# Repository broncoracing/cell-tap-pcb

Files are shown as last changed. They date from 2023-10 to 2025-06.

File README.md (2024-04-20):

# Bronco Racing Segment Monitor PCB

This repository contains the hardware design, firmware, and software calibration scripts for the segment monitor PCB.

The segment monitor contains an STM32f103R8T6 microcontroller which interfaces 15 ADCs (12 external for monitoring cell temperatures and 3 onboard on the PCB.)
A separate break-away board for digital and power isolation is also included.

## Hardware details

The thermistor measurement circuit consists of a 10k thermistor (or connector for a thermistor), a precision 10k reference resistor, and a filter capacitor (The filter capacitor is mostly important to prevent measurement errors due to the changing input impedance of the microcontroller's analog pins when they sample the voltage, this is likely a very small effect that wouldn't cause large errors anyway).

The reference resistor and thermistor form a voltage divider circuit, which allows the resistance of the thermistor to be determined by reading the center voltage.

The circuit is designed specifically to work with 10k NTC thermistors, but it would likely work with any thermistor with a resistance in the 1k-100k range.

Each external thermistor connector also has an LED located next to the connector. This LED indicates whether the thermistor's resistance is valid. If the thermistor is within a reasonable range, the LED will be off. If the microcontroller detects too high or low of a voltage (indicating a short circuit or disconnected thermistor) the LED is turned on. Upon powering up the LEDs will all turn on and off in sequence to verify that the LEDs themselves function correctly.

On the back side of the board (opposite the microcontroller) each cell tap connection connects to an SMD fuse and a trace which leads to the cell tap connector. These fuses are located close to the cell tap connection to meet FSAE rules for fusing of tractive system wires, and eliminate the need for inline fuses on each cell tap wire. 
Due to a minor design oversight, the fuses on the endmost cell taps can be damaged or knocked off the board if the busbars for the Radlok maintenance plugs are rotated too far inwards when the segment is being assembled. Take care when assembling or disassembling the segments to avoid this issue.

## Firmware documentation
The firmware reads data from all the connected thermistors and sends them over the CAN bus at 100ms intervals.

To avoid overloading CAN bus with too many concurrent messages, each segment sends out only 4 thermistor values in each message, and rotates which thermistor temperatures are sent out in each message.

The segment PCB firmware also includes a thermistor calibration routine, which stores measured ADC values for three different temperatures  the Steinhart-Hart equation as described below in the Performance Testing & Analysis section. To perform this calibration, a simple CAN protocol similar to the one utilized by the CAN bootloader was developed. This protocol consists of four commands to perform the following actions:
- Clear calibration data
- Record resistances at a given temperature
- Calculate Steinhart-Hart parameters based on three temperature values
- Read out calibration data over CAN bus and print it to the console

In order to simplify the user experience, a Python command line application was developed to execute these commands and interpret the response sent back over the CAN bus.
This script is located at `firmware/scripts/calibrate.py`. Since I was too lazy to make it automatically detect the CAN bus interface, you'll have to manually set it in the script (or upgrade the script to use a command line parameter), it will be something like `/dev/ttyACM*` on linux.

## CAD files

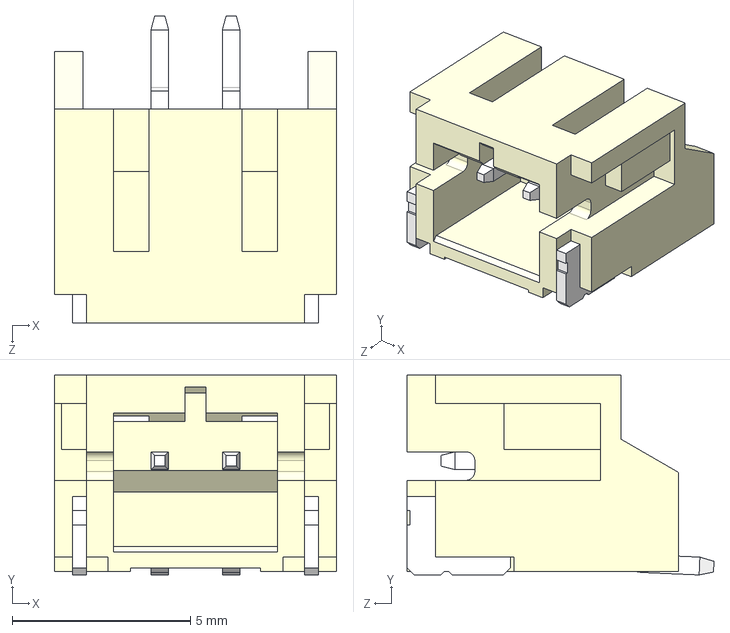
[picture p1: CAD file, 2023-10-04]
3d/S2B-PH-SM4-TB(LF)(SN)--3DModel-STEP-56544.STEP
7.90 x 5.60 x 8.60 mm

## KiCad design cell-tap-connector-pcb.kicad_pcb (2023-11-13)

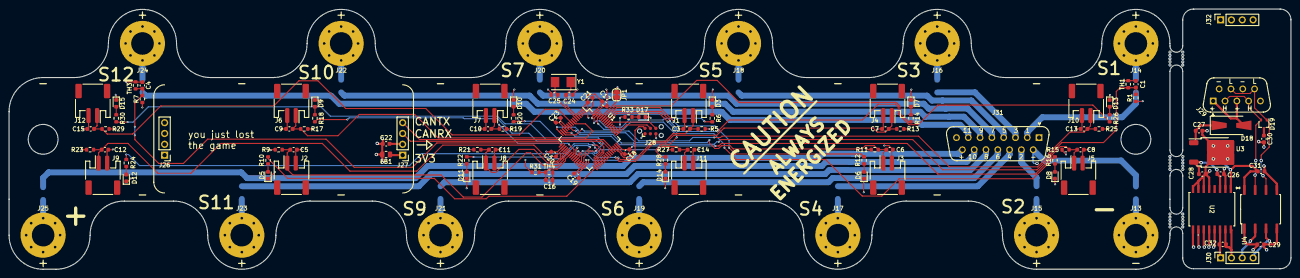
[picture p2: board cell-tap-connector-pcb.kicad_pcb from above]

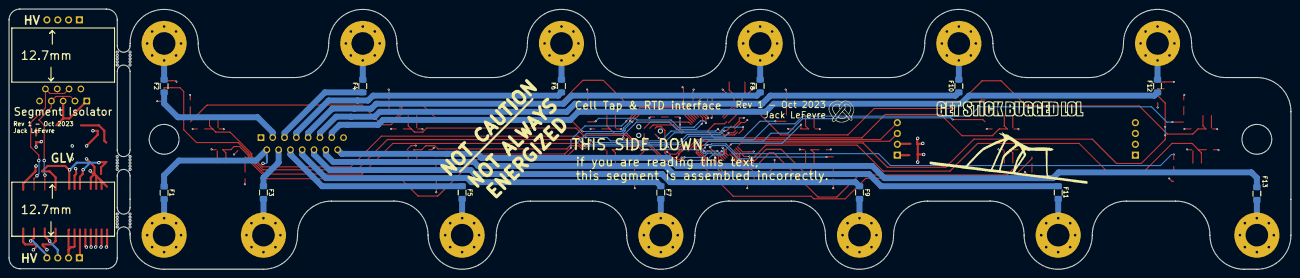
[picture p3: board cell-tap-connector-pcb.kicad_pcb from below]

Board: 4 copper layers, 300.9 x 61.1 mm, 133 parts (14 on the bottom side), 89 nets.

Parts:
C1, C3, C4, C5, C6, C7, C8, C9, C10, C11, C12, C13, C14, C15, C16, C22, C27: 1u; C_0603_1608Metric
C17: 4u7; C_0603_1608Metric
C18, C19, C20, C21, C23, C28, C29, C30, C31: 100n; C_0603_1608Metric
C24, C25: 30p; C_0603_1608Metric
C26, C32: 10u; C_0603_1608Metric
D3, D5, D6, D7, D8, D9, D10, D11, D12, D13, D14, D15, D17: RED 0603; LED_0603_1608Metric
D18: SSB43L; D_SMA-SMB_Universal_Handsoldering
D19: ESDCAN24-2BLY; SOT-323_SC-70
F1, F2, F3, F4, F5, F6, F7, F8, F9, F10, F11, F12, F13: 2A 63VDC 1206; Fuse_1206_3216Metric_Pad1.42x1.75mm_HandSolder
FB1: 100R@100MHz; R_0805_2012Metric
J1, J2, J3, J4, J5, J6, J7, J8, J9, J10, J11, J12: JST S2B-PH-SM4-TB; JST_PH_S2B-PH-SM4-TB_1x02-1MP_P2.00mm_Horizontal
J13, J14, J15, J16, J17, J18, J19, J20, J21, J22, J23, J24, J25: Mounting Hole M5; MountingHole_5.3mm_M5_Pad_Via
J26, J27: Pin Header 0.1" 01x04; PinHeader_1x04_P2.54mm_Vertical
J28: TC2030; Tag-Connect_TC2030-IDC-NL_2x03_P1.27mm_Vertical
J29: Norcomp 172-009-243R021; DSUB-9_Female_Vertical_P2.77x2.84mm
J30, J32: Pin Socket 0.1" 01x04; PinSocket_1x04_P2.54mm_Vertical
J31: 172-015-243R021; DSUB-15_Female_Vertical_P2.77x2.84mm
JP1: SolderJumper_2_Bridged; SolderJumper-2_P1.3mm_Bridged_RoundedPad1.0x1.5mm
NT1: NetTie_2; NetTie-2_SMD_Pad0.5mm
R1, R5, R7, R9, R11, R13, R15, R17, R19, R21, R23, R25, R27, R29, R31: 10k 0.1%; R_0603_1608Metric
R6, R10, R12, R14, R16, R18, R20, R22, R24, R26, R28, R30, R33: 1k; R_0603_1608Metric
TH1, TH3, TH4: 10k NTC ERT-J1VR103J; R_0603_1608Metric
U1: STM32F103R8T6; LQFP-64_10x10mm_P0.5mm
U2: UCC12040DVE; SO_0DVER_TEX
U3: L7805CDT; TO-252-2
U4: ISO1050DUB; SOP-8_6.62x9.15mm_P2.54mm
Y1: 8MHz 20pF; Crystal_SMD_5032-2Pin_5.0x3.2mm
mouse-bite-3mm-slot, mouse-bite-3mm-slot#2, mouse-bite-3mm-slot#3: VAL**; mouse-bite-3mm-slot

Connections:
+3.3VA: C22.1, C23.1, FB1.2, R1.1, R5.1, R7.1, R9.1, R11.1, R13.1, R15.1, R17.1, R19.1, R21.1, R23.1, R25.1, R27.1, R29.1, R31.1, U1.13 (VDDA)
+3V3: C17.1, C18.1, C19.1, C20.1, C21.1, FB1.1, J27.1, J28.1 (VCC), U1.1 (VBAT), U1.19 (VDD), U1.32 (VDD), U1.48 (VDD), U1.64 (VDD)
/Cell PCB/HSE_IN: C24.1, U1.5 (PD0), Y1.1
/Cell PCB/HSE_OUT: C25.1, U1.6 (PD1), Y1.2
/Cell PCB/cell1-p: F2.1, J31.2
/Cell PCB/cell2-p: F3.1, J31.10
/Cell PCB/cell3-p: F4.1, J31.3
/Cell PCB/cell4-p: F5.1, J31.11 (P111)
/Cell PCB/cell5-p: F6.1, J31.4
/Cell PCB/cell6-p: F7.1, J31.12
/Cell PCB/cell7-p: F8.1, J31.5
/Cell PCB/cell8-p: F9.1, J31.13
/Cell PCB/cell9-p: F10.1, J31.6
/Cell PCB/cell10-p: F11.1, J31.14
/Cell PCB/cell11-p: F12.1, J31.7
/Cell PCB/segment-n: F1.1, J31.9, NT1.1
/Cell PCB/segment-p: F13.1, J31.15
/Cell PCB/status-led: R33.1, U1.50 (PA15)
/Isolator/3v3@HV: C29.1, C32.1, J30.1, U2.14 (VISO), U4.1 (VCC1)
/Isolator/5V0@GLV: C26.1, C28.1, C31.2, U2.1 (EN), U2.3 (VINP), U3.3 (OUT), U4.8 (VCC2)
/Isolator/CANH: D19.2 (A2), J29.2, J29.4, U4.7 (CANH)
/Isolator/CANL: D19.1 (A1), J29.7, J29.9, U4.6 (CANL)
/Isolator/CANRX: J30.3, U4.2 (RXD)
/Isolator/CANTX: J30.4, U4.3 (TXD)
/Isolator/GLV+: D18.2 (A), J29.1, J29.3
/Isolator/GLV-: C26.2, C27.2, C28.2, C30.2, C31.1, J29.6, J29.8, U2.2 (GNDP), U2.5 (SYNC_OK), U2.6 (NC), U2.7 (NC), U2.8 (NC), U3.2 (GND), U4.5 (GND2)
/Isolator/GND@HV: C29.2, C32.2, J30.2, U2.9 (GNDS), U2.10 (NC), U2.11 (NC), U2.12 (NC), U2.13 (SEL), U2.15 (GNDS), U2.16 (GNDS), U4.4 (GND1)
CANRX: J27.3, U1.44 (PA11)
CANTX: J27.4, U1.45 (PA12)
GND: C1.2, C3.2, C4.2, C5.2, C6.2, C7.2, C8.2, C9.2, C10.2, C11.2, C12.2, C13.2, C14.2, C15.2, C16.2, C17.2, C18.2, C19.2, C20.2, C21.2, C22.2, C23.2, C24.2, C25.2, D3.1 (K), D5.1 (K), D6.1 (K), D7.1 (K), D8.1 (K), D9.1 (K), D10.1 (K), D11.1 (K), D12.1 (K), D13.1 (K), D14.1 (K), D15.1 (K), D17.1 (K), J1.2, J2.2, J3.2, J4.2, J5.2, J6.2, J7.2, J8.2, J9.2, J10.2, J11.2, J12.2, J27.2, J28.5 (GND), JP1.1 (A), NT1.2, TH1.2, TH3.2, TH4.2, U1.12 (VSSA), U1.18 (VSS), U1.31 (VSS), U1.47 (VSS), U1.63 (VSS)
unnamed: D3.2 (A), R6.2
unnamed: D5.2 (A), R10.2
unnamed: D6.2 (A), R12.2
unnamed: D7.2 (A), R14.2
unnamed: D8.2 (A), R16.2
unnamed: D9.2 (A), R18.2
unnamed: D10.2 (A), R20.2
unnamed: D11.2 (A), R22.2
unnamed: D12.2 (A), R24.2
unnamed: D13.2 (A), R26.2
unnamed: D14.2 (A), R28.2
unnamed: D15.2 (A), R30.2
unnamed: D17.2 (A), R33.2
unnamed: C27.1, D18.1 (K), U3.1 (IN)
unnamed: C30.1, D19.3 (common)
unnamed: F1.2, J13.1
unnamed: F2.2, J14.1
unnamed: F3.2, J15.1
unnamed: F4.2, J16.1
unnamed: F5.2, J17.1
unnamed: F6.2, J18.1
unnamed: F7.2, J19.1
unnamed: F8.2, J20.1
unnamed: F9.2, J21.1
unnamed: F10.2, J22.1
unnamed: F11.2, J23.1
unnamed: F12.2, J24.1
unnamed: F13.2, J25.1
unnamed: JP1.2 (B), U1.60 (BOOT0)
STAT0: R16.1, U1.56 (PB4)
STAT1: R26.1, U1.57 (PB5)
STAT2: R12.1, U1.58 (PB6)
STAT3: R14.1, U1.59 (PB7)
STAT4: R28.1, U1.61 (PB8)
STAT5: R6.1, U1.62 (PB9)
STAT6: R22.1, U1.29 (PB10)
STAT7: R20.1, U1.30 (PB11)
STAT8: R10.1, U1.33 (PB12)
STAT9: R18.1, U1.34 (PB13)
STAT10: R24.1, U1.35 (PB14)
STAT11: R30.1, U1.36 (PB15)
SWCLK: J28.4 (SWCLK), U1.49 (PA14)
SWDIO: J28.2 (SWDIO), U1.46 (PA13)
SWO: J28.6 (SWO), U1.55 (PB3)
TEMP0: C8.1, J5.1, R15.2, U1.14 (PA0)
TEMP1: C13.1, J10.1, R25.2, U1.15 (PA1)
TEMP2: C6.1, J3.1, R11.2, U1.16 (PA2)
TEMP3: C7.1, J4.1, R13.2, U1.26 (PB0)
TEMP4: C14.1, J11.1, R27.2, U1.27 (PB1)
TEMP5: C3.1, J1.1, R5.2, U1.25 (PC5)
TEMP6: C11.1, J8.1, R21.2, U1.21 (PA5)
TEMP7: C10.1, J7.1, R19.2, U1.24 (PC4)
TEMP8: C5.1, J2.1, R9.2, U1.22 (PA6)
TEMP9: C9.1, J6.1, R17.2, U1.8 (PC0)
TEMP10: C12.1, J9.1, R23.2, U1.20 (PA4)
TEMP11: C15.1, J12.1, R29.2, U1.9 (PC1)
TEMP12: C4.1, R7.2, TH3.1, U1.17 (PA3)
TEMP13: C1.1, R1.2, TH1.1, U1.11 (PC3)
TEMP14: C16.1, R31.2, TH4.1, U1.23 (PA7)

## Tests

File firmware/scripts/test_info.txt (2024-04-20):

--- TEST 1 ---
File: candump-2024-04-06 211554.log
Starting water temp: 46.0C
Start time: 9:18pm
Ending temp: 46.2C
Ending time: 9:24
(timestamp 1712453035.319857)

Unsure of calibration accuracy for this test. The first segment cooled much less; this indicates that higher flow rate is required.
--- TEST 2 ---
File: candump-2024-04-06_214447.log 
Start time: 9:45
(timestamp 1712454359.600237)
Start water temp: 48.4
Temp switch time: 9:51
(timestamp 1712454697.084706)
flow rate tests: 5gal in 1:18 (14.8in^3/sec)
switched to cool water.
Flow rate tests: 5gal in 1:30 (12.8in^3/sec)
outlet water temp 25.5 30 sec after start
Water flow stop time: 9:55
(timestamp 1712454924.238978)
End inlet water temp: 11.8C

It appears the segment wasn't calibrated well at room temperature; it thought it started the test out at 33C :(

--- TEST 3 ---
File: candump-2024-04-06_221804.log
Starting time: 10:18
(timestamp 1712456355.978423)
Initial water temp: 47.3C
Room temp: 24.5C
Flow rate: 1:25 for 5gal (13.6in^3/s)
Switched to cool water at 10:23
(timestamp 1712456619.035202)
flow rate: 1:40 for 5gal (11.55 in^3/sec)
End time: 10:29
(Timestamp 1712456964.507980)
End water temp: 10.3C

This test went much more smoothly. The cell temperature sensors were calibrated to room temp (24C) a few minutes before the test.

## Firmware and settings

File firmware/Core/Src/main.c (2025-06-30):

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
/* Includes ------------------------------------------------------------------*/
#include "main.h"

/* USER CODE BEGIN Includes */
#include "can-ids/CAN.h"
#include <string.h>
#include <math.h>
/* USER CODE END Includes */

/* USER CODE BEGIN PD */

// TODO Read from flash
uint32_t BOARD_ID = 0;
/* USER CODE END PD */

ADC_HandleTypeDef hadc1;
DMA_HandleTypeDef hdma_adc1;

CAN_HandleTypeDef hcan;

void SystemClock_Config(void);
static void MX_GPIO_Init(void);
static void MX_DMA_Init(void);
static void MX_ADC1_Init(void);
static void MX_CAN_Init(void);
/* USER CODE BEGIN 0 */
GPIO_TypeDef* status_ports[N_STATUS_LEDS] = {
  STAT0_GPIO_Port,
  STAT1_GPIO_Port,
  STAT2_GPIO_Port,
  STAT3_GPIO_Port,
  STAT4_GPIO_Port,
  STAT5_GPIO_Port,
  STAT6_GPIO_Port,
  STAT7_GPIO_Port,
  STAT8_GPIO_Port,
  STAT9_GPIO_Port,
  STAT10_GPIO_Port,
  STAT11_GPIO_Port,
};
uint16_t status_pins[N_STATUS_LEDS] = {
  STAT0_Pin,
  STAT1_Pin,
  STAT2_Pin,
  STAT3_Pin,
  STAT4_Pin,
  STAT5_Pin,
  STAT6_Pin,
  STAT7_Pin,
  STAT8_Pin,
  STAT9_Pin,
  STAT10_Pin,
  STAT11_Pin,
};

uint8_t adc_to_channel_mapping[N_ADC_CHANNELS] = {
  0, 1, 2, 12, 10, 6, 8, 14, 3, 4, 9, 11, 13, 7, 5
};



volatile uint16_t adc_readings[N_ADC_CHANNELS];

int16_t temperatures[N_ADC_CHANNELS];

// Orion BMS CAN data
uint8_t orion_data_ready = 0; // stores whether data is available to send yet
const uint8_t thermistor_module_number = 0;
int8_t pack_min_temperature; // in degrees C
uint8_t pack_min_idx;
int8_t pack_max_temperature; // in degrees C
uint8_t pack_max_idx;
int32_t pack_temp_sum; // for calculating average temperature
uint8_t pack_temp_samples;
const uint8_t thermistor_count = 12 * 7;

const uint8_t orion_bms_address_claim[8] = {
  0xF3, 0x00, 0x80, 0xF3, 0x00, 0x40, 0x1E, 0x90
};


uint32_t write_cal_data(struct ThermistorCal_T* data);


float compute_resistance(uint16_t adc_reading) {
  float adc_float = (float) adc_reading;
  float voltage_fac = adc_float / ((float) 0x1000); // input voltage as a fraction of VDDA
  const float ref_resistance = 10000.0; // precision reference resistor value
  float rtd_resistance = ref_resistance * ((1.0 / voltage_fac) - 1);
  return rtd_resistance;
}

float c2k(float c) {
    return c + 273.15;
}
float k2c(float k) {
    return k - 273.15;
}

struct SteinhartHartParameters compute_parameters(float r1, float t1, float r2, float t2, float r3, float t3) {
    float ln_r1 = logf(r1);
    float ln_r2 = logf(r2);
    float ln_r3 = logf(r3);

    float Y_1 = 1.0 / c2k(t1);
    float Y_2 = 1.0 / c2k(t2);
    float Y_3 = 1.0 / c2k(t3);

    float gamma_2 = (Y_2 - Y_1) / (ln_r2 - ln_r1);
    float gamma_3 = (Y_3 - Y_1) / (ln_r3 - ln_r1);

    float C = ((gamma_3 - gamma_2) / (ln_r3 - ln_r2)) * 1.0 / (ln_r1 + ln_r2 + ln_r3);

    float B = gamma_2 - C * (ln_r1 * ln_r1 + ln_r1 * ln_r2 + ln_r2 * ln_r2);

    float A = Y_1 - (B + C * ln_r1 * ln_r1) * ln_r1;

    struct SteinhartHartParameters params = {A,B,C};
    return params;
}

float compute_temperature(struct SteinhartHartParameters* p, float r) {
  float ln_r = logf(r);
  float t_inv = p->A + p->B * ln_r + p->C * ln_r * ln_r * ln_r;
  float temp_kelvin = 1.0 / t_inv;
  return k2c(temp_kelvin);
}

void can_send_float(uint8_t errno, float f1) {
  // Message header
  CAN_TxHeaderTypeDef m;
  // Use standard ID
  m.IDE = CAN_ID_STD;
  // Set message ID
  m.StdId = CELL_TAP_CAL_RESP_ID + BOARD_ID;
  // Use CAN_RTR_DATA to transmit data
  // We may use CAN_RTR_REMOTE to request things to send data in the future
  m.RTR = CAN_RTR_DATA;
  // Amount of data
  m.DLC = 8;

  // Data to send
  uint8_t data_u8[8];

  uint32_t* int_value = (uint32_t*) &f1;
  data_u8[4] = (*int_value >> 24) & 0xff;
  data_u8[5] = (*int_value >> 16) & 0xff;
  data_u8[6] = (*int_value >> 8) & 0xff;
  data_u8[7] = (*int_value) & 0xff;
  data_u8[0] = errno;
  data_u8[1] = 0;
  data_u8[2] = 0;
  data_u8[3] = 0;

  // Send a message
  uint32_t mailbox;
  HAL_CAN_AddTxMessage(&hcan, &m, data_u8, &mailbox);
  
  // Wait for message to be sent. This is usually not needed.
  while (HAL_CAN_IsTxMessagePending(&hcan, mailbox));
}

uint8_t cal_cmd(uint8_t cmd, float value) {
  uint8_t errno = 0;
  
  // read current calibration from flash
  struct ThermistorCal_T current_cal;
  struct ThermistorCal_T* memcpy_source = CAL_TABLE;
  memcpy(&current_cal, memcpy_source, sizeof(struct ThermistorCal_T));
  switch(cmd) {
    case 0:
      // clear calibration
      struct ThermistorCal_T blank_cal = {0};
      if(write_cal_data(&blank_cal) > 0) errno = 1;
      break;
    case 1:
    case 2:
    case 3:
      current_cal.temps[cmd - 1] = value;
      for(uint8_t i = 0; i < N_ADC_CHANNELS; ++i) {
        // TODO use filtered adc readings
        uint16_t reading = adc_readings[i];
        if(reading < ADC_ERR_LOW || reading > ADC_ERR_HIGH) {
          errno = 3;
          break;
        }
        current_cal.adc_readings[i][cmd - 1] = adc_readings[i];
      }
      if(errno == 0) {
        current_cal.temp_calibrations[cmd - 1] = 1;
        if(write_cal_data(&current_cal) > 0) errno = 1;
      }
      break;
    case 4:
      // Verify that all three calibration points have been read, otherwise the result will be nonsense
      if(current_cal.temp_calibrations[0] && current_cal.temp_calibrations[1] && current_cal.temp_calibrations[2]) {
        float t1 = current_cal.temps[0];
        float t2 = current_cal.temps[1];
        float t3 = current_cal.temps[2];
        // now low/mid/high_cal_idx should be in order
        for(uint8_t i = 0; i < N_ADC_CHANNELS; ++i) {
          float r1 = compute_resistance(current_cal.adc_readings[i][0]);
          float r2 = compute_resistance(current_cal.adc_readings[i][1]);
          float r3 = compute_resistance(current_cal.adc_readings[i][2]);

          // previous debugging code
          // can_send_float(200, r1);
          // can_send_float(201, t1);
          // can_send_float(202, r2);
          // can_send_float(203, t2);
          // can_send_float(204, r3);
          // can_send_float(205, t3);

          struct SteinhartHartParameters params = compute_parameters(r1, t1, r2, t2, r3, t3);
          if(isnan(params.A) || isnan(params.B) || isnan(params.C)) {
            errno = 5;
            break;
          }

          current_cal.parameters[i] = params;
        }
      } else {
        errno = 4;
        break;
      }

      current_cal.abc_calibration = 1;

      if(write_cal_data(&current_cal) > 0) errno = 1;
      break;
    case 5: // dump out calibration values
        // ABC Values
        for(uint8_t i = 0; i < N_ADC_CHANNELS; ++i) {
          can_send_float(20 + i, current_cal.parameters[i].A);
        }
        for(uint8_t i = 0; i < N_ADC_CHANNELS; ++i) {
          can_send_float(40 + i, current_cal.parameters[i].B);
        }
        for(uint8_t i = 0; i < N_ADC_CHANNELS; ++i) {
          can_send_float(60 + i, current_cal.parameters[i].C);
        }

        // Calib. temps
        can_send_float(80, current_cal.temps[0]);
        can_send_float(81, current_cal.temps[1]);
        can_send_float(82, current_cal.temps[2]);

        // ADC Readings
        for(uint8_t i = 0; i < N_ADC_CHANNELS; ++i) {
          can_send_float(100 + i, (float) current_cal.adc_readings[i][0]);
        }
        for(uint8_t i = 0; i < N_ADC_CHANNELS; ++i) {
          can_send_float(120 + i, (float) current_cal.adc_readings[i][1]);
        }
        for(uint8_t i = 0; i < N_ADC_CHANNELS; ++i) {
          can_send_float(140 + i, (float) current_cal.adc_readings[i][2]);
        }
      break;

    default:
      errno = 2;
  }

  // send response
  // Message header
  CAN_TxHeaderTypeDef m;
  // Use standard ID
  m.IDE = CAN_ID_STD;
  // Set message ID
  m.StdId = CELL_TAP_CAL_RESP_ID + BOARD_ID;
  // Use CAN_RTR_DATA to transmit data
  // We may use CAN_RTR_REMOTE to request things to send data in the future
  m.RTR = CAN_RTR_DATA;
  // Amount of data
  m.DLC = CELL_TAP_CAL_RESP_DLC;

  // Data to send
  uint8_t data[1];
  data[0] = errno;

  // Send a message
  uint32_t mailbox;
  HAL_CAN_AddTxMessage(&hcan, &m, data, &mailbox);
  // Wait for message to be sent. This is usually not needed.
  while (HAL_CAN_IsTxMessagePending(&hcan, mailbox));
  return 0;
}

void update_orion_bms_data(int8_t t, uint8_t idx) {
  pack_temp_sum += t;
  pack_temp_samples ++;
  if(t < pack_min_temperature) {
    pack_min_temperature = t;
    pack_min_idx = idx;
  }
  if(t > pack_max_temperature) {
    pack_max_temperature = t;
    pack_max_idx = idx;
  }
}

void reset_orion_bms_data(void) {
  pack_max_temperature = INT8_MIN;
  pack_min_temperature = INT8_MAX;
  pack_temp_sum = 0;
  pack_temp_samples = 0;

  for(uint8_t i = 0; i < 12; ++i) {
    int8_t temp_i8 = (int8_t)(temperatures[i] / 100);
    update_orion_bms_data(temp_i8, i);
  }
}

// CAN Interrupt handler. Called whenever a new CAN frame is received.
void can_irq(CAN_HandleTypeDef *pcan) {
  // Message header
  CAN_RxHeaderTypeDef msg;
  // Message data. Only filled with as much data as the message contained, the rest is garbage.
  uint8_t data[8];

  // Read the next CAN frame
  HAL_CAN_GetRxMessage(pcan, CAN_RX_FIFO0, &msg, data);

  // Only accept standard CAN IDs, we don't use extended IDs.
  if(msg.IDE == CAN_ID_STD) { 
    switch (msg.StdId)
      {
      // Add cases for each CAN ID you want to handle

      // ID 0xB0 is a bootloader command, so reset the mcu when received.
      case BOOTLOADER_ID:
        __NVIC_SystemReset(); // Reset to bootloader
        break;
      
      case CELL_TAP_CAL_CMD_ID: // calibration command
        uint8_t command = read_field_u8(&CELL_TAP_CAL_CMD_cmd, data);
        uint32_t int_value = (data[1] << 24) + (data[2] << 16) + (data[3] << 8) + data[4];
        float value = *(float *) &int_value; // reinterpret bytes as float without doing conversion

        cal_cmd(command, value);

      default:
        // Board 0 collects data and sends it to the orion BMS
        if(BOARD_ID == 0){
          // check if the message is from a segment board
          if(msg.StdId >= CELL_TAP_1_1_ID && msg.StdId < CELL_TAP_7_1_ID + 4) {
            if(msg.StdId % 4 != 3) { // don't read the board thermistors, only cells
              uint8_t board_no = (msg.StdId - CELL_TAP_1_1_ID) / 4;
              uint8_t message_no = msg.StdId % 4;
              uint8_t start_thermistor_idx = board_no * 12 + message_no * 4;
              // record max/min temperature
              int16_t* temps = (int16_t*) data;
              for(uint8_t i = 0; i < 4; ++i) {
                int16_t temp = __builtin_bswap16(temps[i]);
                int8_t temp_i8 = (int8_t) (temps[i] / 100);
                update_orion_bms_data(temp_i8, start_thermistor_idx + i);
              }
            }
          }

        }
        break;
      }
  }
}

void can_transmit_orion_bms(void) {
  // Message header
  CAN_TxHeaderTypeDef m;
  // Use standard ID
  m.IDE = CAN_ID_EXT;
  // Set message ID
  m.ExtId = 0x1839F380;
  // Use CAN_RTR_DATA to transmit data
  // We may use CAN_RTR_REMOTE to request things to send data in the future
  m.RTR = CAN_RTR_DATA;
  // Amount of data
  m.DLC = 8;

  // Data to send
  uint8_t data[8];

  int32_t average_temp = pack_temp_sum / pack_temp_samples;
  data[0] = thermistor_module_number;
  data[1] = pack_min_temperature;
  data[2] = pack_max_temperature;
  data[3] = (int8_t) average_temp;
  data[4] = thermistor_count;
  data[5] = pack_max_idx;
  data[6] = pack_min_idx;

  // Checksum 8-bit
  // (sum of all bytes + 0x39 + length)
  uint8_t checksum = 0;
  for(int i = 0; i < 7; ++i) {
    checksum += data[i];
  }
  checksum += 0x39;
  checksum += 8;

  data[7] = checksum;

  // Send a message
  uint32_t mailbox;
  HAL_CAN_AddTxMessage(&hcan, &m, data, &mailbox);
  // Wait for message to be sent. This is usually not needed.
  while (HAL_CAN_IsTxMessagePending(&hcan, mailbox));
}

void can_transmit_orion_bms_address_claim(void) {
  // Message header
  CAN_TxHeaderTypeDef m;
  // Use standard ID
  m.IDE = CAN_ID_EXT;
  // Set message ID
  m.ExtId = 0x18EEFF80;
  // Use CAN_RTR_DATA to transmit data
  // We may use CAN_RTR_REMOTE to request things to send data in the future
  m.RTR = CAN_RTR_DATA;
  // Amount of data
  m.DLC = 8;

  // Send a message
  uint32_t mailbox;
  HAL_CAN_AddTxMessage(&hcan, &m, orion_bms_address_claim, &mailbox);
  // Wait for message to be sent. This is usually not needed.
  while (HAL_CAN_IsTxMessagePending(&hcan, mailbox));
}

// We only send one CAN message each time to save CAN bus resources.
static uint8_t can_message_idx = 0;

void can_transmit_temperatures(void) {
  // Message header
  CAN_TxHeaderTypeDef m;
  // Use standard ID
  m.IDE = CAN_ID_STD;
  // Set message ID
  m.StdId = CELL_TAP_1_1_ID + can_message_idx + 4 * BOARD_ID;
  // Use CAN_RTR_DATA to transmit data
  // We may use CAN_RTR_REMOTE to request things to send data in the future
  m.RTR = CAN_RTR_DATA;
  // Amount of data
  m.DLC = CELL_TAP_1_1_DLC;

  // Data to send
  uint8_t data[8];

  switch(can_message_idx) {
    case 0:
      data[0] = (temperatures[0] >> 8) & 0xFF;
      data[1] = temperatures[0] & 0xFF;
      data[2] = (temperatures[1] >> 8) & 0xFF;
      data[3] = temperatures[1] & 0xFF;
      data[4] = (temperatures[2] >> 8) & 0xFF;
      data[5] = temperatures[2] & 0xFF;
      data[6] = (temperatures[3] >> 8) & 0xFF;
      data[7] = temperatures[3] & 0xFF;
      break;
    case 1:
      data[0] = (temperatures[4] >> 8) & 0xFF;
      data[1] = temperatures[4] & 0xFF;
      data[2] = (temperatures[5] >> 8) & 0xFF;
      data[3] = temperatures[5] & 0xFF;
      data[4] = (temperatures[6] >> 8) & 0xFF;
      data[5] = temperatures[6] & 0xFF;
      data[6] = (temperatures[7] >> 8) & 0xFF;
      data[7] = temperatures[7] & 0xFF;
      break;
    case 2:
      data[0] = (temperatures[8] >> 8) & 0xFF;
      data[1] = temperatures[8] & 0xFF;
      data[2] = (temperatures[9] >> 8) & 0xFF;
      data[3] = temperatures[9] & 0xFF;
      data[4] = (temperatures[10] >> 8) & 0xFF;
      data[5] = temperatures[10] & 0xFF;
      data[6] = (temperatures[11] >> 8) & 0xFF;
      data[7] = temperatures[11] & 0xFF;
      break;
    case 3:
      data[0] = (temperatures[12] >> 8) & 0xFF;
      data[1] = temperatures[12] & 0xFF;
      data[2] = (temperatures[13] >> 8) & 0xFF;
      data[3] = temperatures[13] & 0xFF;
      data[4] = (temperatures[14] >> 8) & 0xFF;
      data[5] = temperatures[14] & 0xFF;

      int16_t max_temp = INT16_MIN;
      for(int i = 0; i < 12; ++i) {
        int16_t temp = temperatures[i];
        if(temp > max_temp) {
          max_temp = temp;
        }
      }
      data[6] = (max_temp >> 8) & 0xFF;
      data[7] = max_temp & 0xFF;
      break;
    default:
      Error_Handler();
      break;
  }

  // Send a message
  uint32_t mailbox;
  HAL_CAN_AddTxMessage(&hcan, &m, data, &mailbox);
  // Wait for message to be sent. This is usually not needed.
  while (HAL_CAN_IsTxMessagePending(&hcan, mailbox));
  
  // Board 0 sends data to the BMS
  if(BOARD_ID == 0) {
    // only send orion data once all data is out
    if(can_message_idx == 3) {
      orion_data_ready = 1;
    }

    if(orion_data_ready) {
      can_transmit_orion_bms();
      reset_orion_bms_data();
    }

    // send address claim (every 200ms)
    if(can_message_idx % 2 == 0) {
      can_transmit_orion_bms_address_claim();
    }
  }
  
  can_message_idx = (can_message_idx + 1) % 4;
}


uint8_t __fls_wr(const uint32_t *page, const uint32_t *buf, uint32_t len)
{
  __HAL_FLASH_CLEAR_FLAG(FLASH_FLAG_EOP | FLASH_FLAG_PGERR | FLASH_FLAG_WRPERR);

  uint32_t erase_err;
  FLASH_EraseInitTypeDef erase_page = {
      FLASH_TYPEERASE_PAGES,
      FLASH_BANK_1,
      (uint32_t)page, 1};

  if (HAL_OK != HAL_FLASHEx_Erase(&erase_page, &erase_err)) {
    return 1;
  }

  for (uint32_t i = 0; i < len; ++i)
  {
    HAL_StatusTypeDef res = HAL_FLASH_Program(FLASH_TYPEPROGRAM_WORD, (uint32_t)page, *buf);
    if (HAL_OK != res)
    {
      __NOP();
      return 2;
    }
    ++page;
    ++buf;
  }
  __NOP();

  return 0;
}

uint8_t fls_wr(const uint32_t *page, const uint32_t *buf, uint32_t len)
{
  // does flash equal buffer already?
  if (0 == memcmp(page, buf, 4 * len))
  {
    return 0;
  }

  HAL_FLASH_Unlock();
  uint8_t r = __fls_wr(page, buf, len);
  HAL_FLASH_Lock();
  if (r)
  {
    return r;
  }

  // verify
  if (0 != memcmp(page, buf, 4 * len))
  {
    return 10;
  }

  return 0;
}


uint32_t write_cal_data(struct ThermistorCal_T* data) {
  return fls_wr(CAL_TABLE, (uint32_t*) data, sizeof(struct ThermistorCal_T) / sizeof(uint32_t));
}

/* USER CODE END 0 */

/**
  * @brief  The application entry point.
  * @retval int
  */
int main(void)
{
  /* USER CODE BEGIN 1 */
  // necessary for bootloader
  SCB->VTOR = (uint32_t)0x08003000;
  /* USER CODE END 1 */

  /* MCU Configuration--------------------------------------------------------*/

  /* Reset of all peripherals, Initializes the Flash interface and the Systick. */
  HAL_Init();

  /* Configure the system clock */
  SystemClock_Config();

  /* USER CODE BEGIN SysInit */

  if(FLASH_VARS->board.id >= 10 || FLASH_VARS->board.id <= 16) {
    // Board id in the proper range :)
      BOARD_ID = FLASH_VARS->board.id - 10;
  }

  /* USER CODE END SysInit */

  /* Initialize all configured peripherals */
  MX_GPIO_Init();
  MX_DMA_Init();
  MX_ADC1_Init();
  MX_CAN_Init();
  /* USER CODE BEGIN 2 */
  
  HAL_ADCEx_Calibration_Start(&hadc1);


  for(uint8_t i = 0; i < 12; ++i) {
    HAL_GPIO_WritePin(status_ports[i], status_pins[i], GPIO_PIN_SET);
    HAL_Delay(50);
  }
  for(uint8_t i = 0; i < 12; ++i) {
    HAL_GPIO_WritePin(status_ports[i], status_pins[i], GPIO_PIN_RESET);
    HAL_Delay(50);
  }

  struct ThermistorCal_T* current_cal = CAL_TABLE;

  /* USER CODE END 2 */

  /* Infinite loop */
  /* USER CODE BEGIN WHILE */
  while (1)
  {
    HAL_ADC_Start_DMA(&hadc1, (uint32_t*) adc_readings, N_ADC_CHANNELS);
    HAL_Delay(100);

    for(uint8_t i = 0; i < N_ADC_CHANNELS; ++i) {
      uint8_t channel = adc_to_channel_mapping[i];
      uint16_t reading = adc_readings[i];

      if(current_cal->abc_calibration) {
        float resistance = compute_resistance(reading);
        float temp = compute_temperature(&(current_cal->parameters[i]), resistance);
        temperatures[channel] = (int16_t) (temp * 100.0);
      } else {
        temperatures[channel] = reading;
      }
      if(channel < N_STATUS_LEDS){
        HAL_GPIO_WritePin(status_ports[channel], status_pins[channel], reading < ADC_ERR_LOW || reading > ADC_ERR_HIGH);
      }
    }
    
    // TODO Filtering sensor values
    can_transmit_temperatures();

    /* USER CODE END WHILE */

    /* USER CODE BEGIN 3 */
  }
  /* USER CODE END 3 */
}

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


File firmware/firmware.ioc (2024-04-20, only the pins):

Mcu.UserName=STM32F103R8Tx
PA0-WKUP.Signal=ADCx_IN0
PA1.Signal=ADCx_IN1
PA11.Signal=CAN_RX
PA12.Signal=CAN_TX
PA13.Signal=SYS_JTMS-SWDIO
PA14.Signal=SYS_JTCK-SWCLK
PA15.GPIO_Label=SYS_STAT
PA15.Signal=GPIO_Output
PA2.Signal=ADCx_IN2
PA3.Signal=ADCx_IN3
PA4.Signal=ADCx_IN4
PA5.Signal=ADCx_IN5
PA6.Signal=ADCx_IN6
PA7.Signal=ADCx_IN7
PB0.Signal=ADCx_IN8
PB1.Signal=ADCx_IN9
PB10.GPIO_Label=STAT6
PB10.Signal=GPIO_Output
PB11.GPIO_Label=STAT7
PB11.Signal=GPIO_Output
PB12.GPIO_Label=STAT8
PB12.Signal=GPIO_Output
PB13.GPIO_Label=STAT9
PB13.Signal=GPIO_Output
PB14.GPIO_Label=STAT10
PB14.Signal=GPIO_Output
PB15.GPIO_Label=STAT11
PB15.Signal=GPIO_Output
PB3.Signal=SYS_JTDO-TRACESWO
PB4.GPIO_Label=STAT0
PB4.Signal=GPIO_Output
PB5.GPIO_Label=STAT1
PB5.Signal=GPIO_Output
PB6.GPIO_Label=STAT2
PB6.Signal=GPIO_Output
PB7.GPIO_Label=STAT3
PB7.Signal=GPIO_Output
PB8.GPIO_Label=STAT4
PB8.Signal=GPIO_Output
PB9.GPIO_Label=STAT5
PB9.Signal=GPIO_Output
PC0.Signal=ADCx_IN10
PC1.Signal=ADCx_IN11
PC3.Signal=ADCx_IN13
PC4.Signal=ADCx_IN14
PC5.Signal=ADCx_IN15
PD0-OSC_IN.Signal=RCC_OSC_IN
PD1-OSC_OUT.Signal=RCC_OSC_OUT

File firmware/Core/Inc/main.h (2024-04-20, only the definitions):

#define STAT6_Pin GPIO_PIN_10
#define STAT6_GPIO_Port GPIOB
#define STAT7_Pin GPIO_PIN_11
#define STAT7_GPIO_Port GPIOB
#define STAT8_Pin GPIO_PIN_12
#define STAT8_GPIO_Port GPIOB
#define STAT9_Pin GPIO_PIN_13
#define STAT9_GPIO_Port GPIOB
#define STAT10_Pin GPIO_PIN_14
#define STAT10_GPIO_Port GPIOB
#define STAT11_Pin GPIO_PIN_15
#define STAT11_GPIO_Port GPIOB
#define SYS_STAT_Pin GPIO_PIN_15
#define SYS_STAT_GPIO_Port GPIOA
#define STAT0_Pin GPIO_PIN_4
#define STAT0_GPIO_Port GPIOB
#define STAT1_Pin GPIO_PIN_5
#define STAT1_GPIO_Port GPIOB
#define STAT2_Pin GPIO_PIN_6
#define STAT2_GPIO_Port GPIOB
#define STAT3_Pin GPIO_PIN_7
#define STAT3_GPIO_Port GPIOB
#define STAT4_Pin GPIO_PIN_8
#define STAT4_GPIO_Port GPIOB
#define STAT5_Pin GPIO_PIN_9
#define STAT5_GPIO_Port GPIOB
#define ADC_ERR_HIGH 4000
#define ADC_ERR_LOW 100
#define N_ADC_CHANNELS 15
#define N_STATUS_LEDS 12
#define PAGE_SIZE 0x400
#define CAL_TABLE 0x08010000 - PAGE_SIZE // last 1k block of flash* used to store calibration data
#define APP_BASE ((uint32_t *)(0x08003000))
#define FLASH_VARS ((volatile struct bl_vars_t *)(APP_BASE - 0x100))

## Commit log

2023-10-04 initial layout
    [Isolater.kicad_sch, S2B-PH-SM4-TB(LF)(SN)--3DModel-STEP-56544.STEP, cell-pcb.kicad_sch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]
2023-10-05 more layout and memes
    [Isolater.kicad_sch, cell-pcb.kicad_sch, cell-tap-connector-pcb.kicad_pcb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]
2023-10-23 removed slots
    [Isolater.kicad_sch, cell-pcb.kicad_sch, cell-tap-connector-pcb.kicad_pcb]
2023-11-12 Update kibot.yml to kicad 7
2023-11-12 remove net class labels, which are unsupported by kibot :(
    [Isolater.kicad_sch, cell-pcb.kicad_sch]
2023-11-12 hopefully appease drc checker
    [cell-tap-connector-pcb.kicad_pcb]
2023-11-13 fix drc/erc errors
    [Isolater.kicad_sch, cell-pcb.kicad_sch, cell-tap-connector-pcb.kicad_pcb]
2024-04-20 Created test firmware
    [cell-pcb.kicad_sch]
2024-04-20 added calibration and bootloader support
2024-04-20 update firmware to do calibration and work with orion BMS
    [Isolater.kicad_sch, cell-pcb.kicad_sch, thermistor.kicad_sch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]
2025-06-30 add big/little endian swap for board 0 bms data
    [main.c]

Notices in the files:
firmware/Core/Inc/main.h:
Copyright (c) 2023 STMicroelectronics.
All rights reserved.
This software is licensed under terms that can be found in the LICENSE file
